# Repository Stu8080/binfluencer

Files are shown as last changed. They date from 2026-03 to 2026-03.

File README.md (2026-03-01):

# Binfluencer

A Leeds bin collection reminder built on the Seeed XIAO ESP32-S3. It queries the live Leeds City Council bin API each day and pulses WS2812B LEDs the evening before your bins are due — so you never forget to put them out.

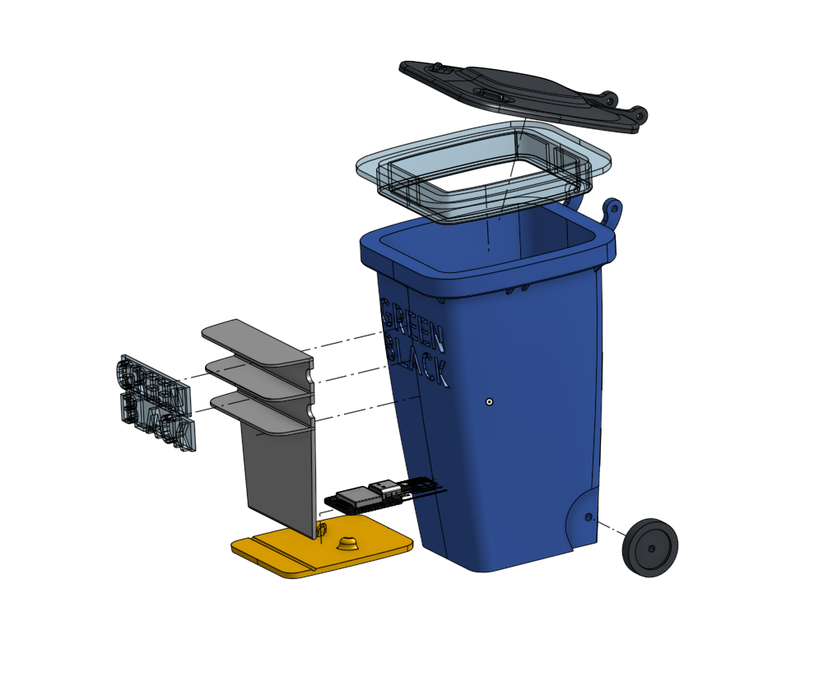
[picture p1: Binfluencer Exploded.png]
Binfluencer Exploded View


---

## How it works

- On boot it connects to WiFi, syncs time via NTP, and fetches your next collection dates from [bins.felixyeung.com](https://bins.felixyeung.com)
- Every **60 seconds** it re-evaluates the schedule (a brief white pulse on the alert strip confirms it's alive)
- Every **24 hours** it re-fetches from the API
- From **7 PM the evening before** a collection, the relevant LEDs start breathing
- On the **collection day itself** the LEDs switch off (bin is already out)

### LED behaviour

| Situation | LEDs |
|---|---|
| Recycling tomorrow evening | Green lettering breathes |
| General waste tomorrow evening | BLACK lettering breathes white |
| Both due tomorrow | Sequences: alert strip → black → green (5 s each) |
| Collection day | All off |
| Schedule check heartbeat | Middle 3 alert strip LEDs pulse once at 50% |

Only one LED channel is ever active at a time to minimise peak current draw.

---

## The enclosure

The housing is a 3D printed miniature wheelie bin. All parts are included in this repo. You will need some 2mm brass rod for the lid hinge and wheels.

### Parts

| File | Material | Notes |
|---|---|---|
| `Wheelie Bin - Bin.stl` | PLA — any colour | Main bin body. Printed in Sunlu Midnight Black |
| `Wheelie Bin - Lid.stl` | PLA — any colour | Snap-fit lid |
| `Wheelie Bin - BLACK.stl` | Translucent PETG | "BLACK" lettering panel, snaps into front of bin |
| `Wheelie Bin - GREEN.stl` | Translucent PETG | "GREEN" lettering panel, snaps into front of bin |
| `Wheelie Bin - Top Light.stl` | Translucent PETG | Alert strip diffuser, seals between lid and bin body |
| `Wheelie Bin - Part 7.stl` | PLA | F-shaped LED mount and light baffle — isolates the two 3-LED channels |
| `Wheelie Bin - Part 8.stl` | PLA | Electronics backing plate |
| `Wheelie Bin - Wheel 1.stl` | PLA | Decorative wheel |
| `Wheelie Bin - Wheel 2.stl` | PLA | Decorative wheel |

Microcontroller used: SEEED Studio's Xiao ESP32-S3: https://thepihut.com/products/seeed-studio-xiao-esp32s3

### Assembly

1. Mount the XIAO ESP32-S3 onto the yellow base plate. You can use a little hot glue or double sided tape. Make sure you've wired +Ve and -Ve to 5v and the three data pins for the addressable LED's
2. Attach the 3-LED strips to the front side of the F-shaped baffle — one strip behind the GREEN lettering, one behind BLACK
3. Snap the translucent GREEN and BLACK lettering panels into the front of the bin
4. Seat the F-shaped assembly inside the bin body, theres a small retainer on the walls to snap it into place
5. Mount the 10-LED alert strip horizontally at the top of the bin light panel, facing outwards — it seals against the lid when closed and glows around the lid edge
6. Close the lid

---

## Hardware

| Component | Details |
|---|---|
| Microcontroller | Seeed XIAO ESP32-S3 |
| LEDs | WS2812B — 3× green channel, 3× black channel, 10× alert strip |
| Power | 5V pin on XIAO → LED +ve; GND → LED −ve |
| Data lines | Separate per channel (not daisy-chained) |

### Wiring

> **Note:** On the XIAO ESP32-S3 the physical D-pin labels do not match GPIO numbers from D6 onwards.

| Physical pin | GPIO | Connect to |
|---|---|---|
| D7 | GPIO 44 | BLACK bin LEDs (3×) |
| D8 | GPIO 7 | GREEN bin LEDs (3×) |
| D9 | GPIO 8 | Alert strip (10×) |
| 5V | — | LED +ve (all strips) |
| GND | — | LED −ve (all strips) |

---

## Software

Built with [PlatformIO](https://platformio.org/) for Arduino framework.

### Dependencies

| Library | Version |
|---|---|
| FastLED | `~3.9.0` (pinned — 3.10.x has a build issue on ESP-IDF 5.3) |
| ArduinoJson | `^7.0.0` |

### Project structure

```
binfluencer/
├── platformio.ini          ← main firmware
├── src/
│   ├── main.cpp            ← setup / loop / LED evaluation
│   ├── config.example.h    ← copy to config.h and fill in your details
│   ├── bins_api.h          ← Leeds bin collection API client
│   ├── led_controller.h    ← FastLED state machine
│   ├── schedule.h          ← date parsing and alert logic
│   └── wifi_manager.h      ← WiFi connection with backoff
└── test_led/               ← standalone LED test (no WiFi/API needed)
    ├── platformio.ini
    └── src/
        ├── main.cpp        ← cycles alert → black → green, 5 s each
        ├── config.h
        └── led_controller.h
```

---

## Setup

### 1. Configure

```bash
cp src/config.example.h src/config.h
```

Edit `src/config.h`:

```cpp
#define WIFI_SSID     "your-ssid"
#define WIFI_PASSWORD "your-password"

#define BINS_POSTCODE "LS1 1AA"   // your postcode
#define BINS_HOUSE    "1"         // your house number
```

Find your premises on [bins.felixyeung.com](https://bins.felixyeung.com) to confirm your postcode and house number are recognised. The premises ID is cached to flash (NVS) after the first successful lookup.

### 2. Flash

```bash
# Main firmware
cd binfluencer
pio run --target upload

# LED test only (no WiFi required)
cd binfluencer/test_led
pio run --target upload
```

### 3. Monitor

```bash
pio device monitor
```

On a successful boot you should see:

```
=== Binfluencer booting ===
[WiFi] Connected. IP: 192.168.x.x
[BOOT] Local time: 2026-03-01 19:00:00 GMT
[API] Found premises: "<<address>>" → id=983201
[Schedule] Next Recycling:    2026-03-06
[Schedule] Next General Waste: 2026-03-13
[BOOT] Setup complete.
```

---

## API

Collection data is sourced from [bins.felixyeung.com](https://bins.felixyeung.com), an unofficial Leeds City Council bin collection API.

```
GET /api/premises?postcode=LS8%201AU
GET /api/jobs?premises={id}
```

The premises ID is stored in NVS after the first lookup so the device only hits the premises endpoint once.

---

## Licence

MIT

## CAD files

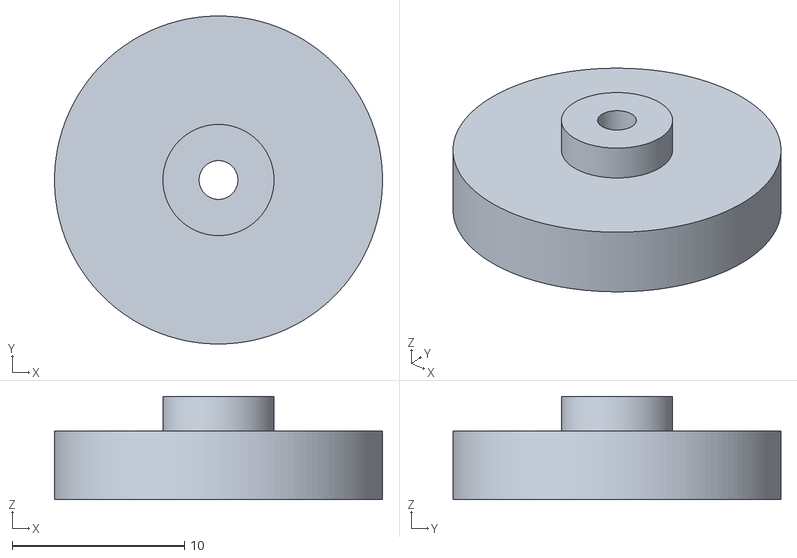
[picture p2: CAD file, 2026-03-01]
Wheelie Bin - Wheel 2.stl.stl
19.1 x 19.1 x 6.00

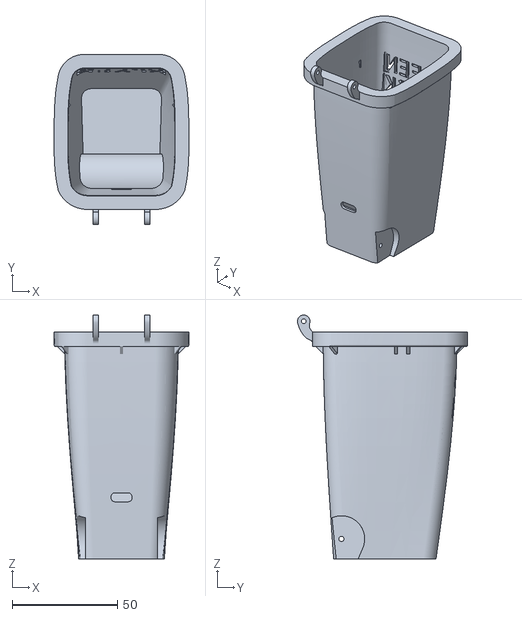
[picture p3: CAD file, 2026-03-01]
Wheelie Bin - Bin.stl.stl
64.1 x 80.9 x 116.0

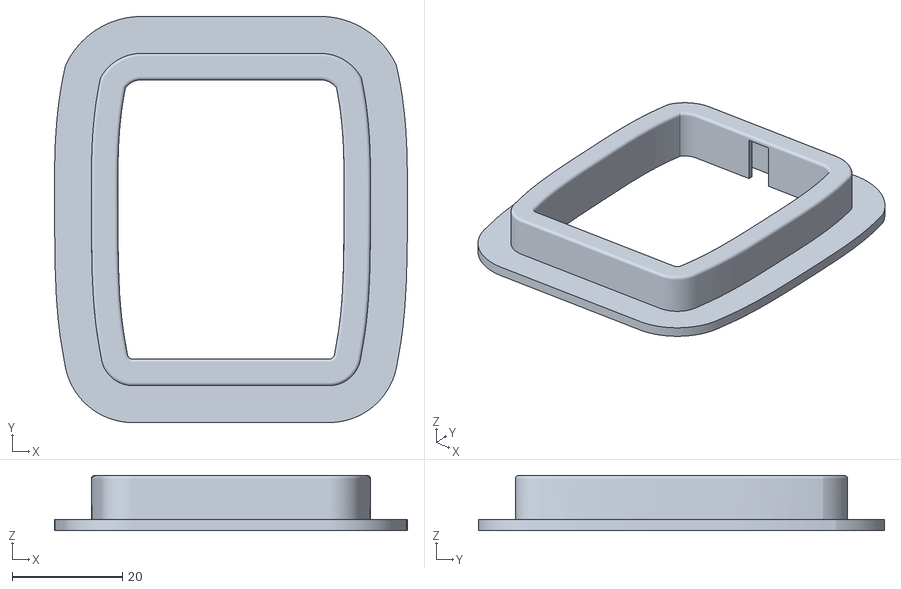
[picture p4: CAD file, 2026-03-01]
Wheelie Bin - Top Light.stl.stl
64.1 x 73.7 x 10.0

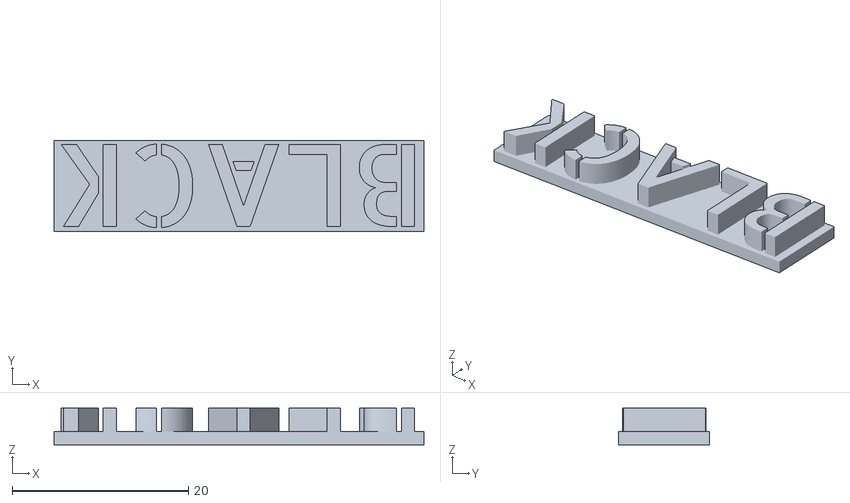
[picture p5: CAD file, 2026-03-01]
Wheelie Bin - BLACK.stl.stl
42.0 x 10.3 x 4.15

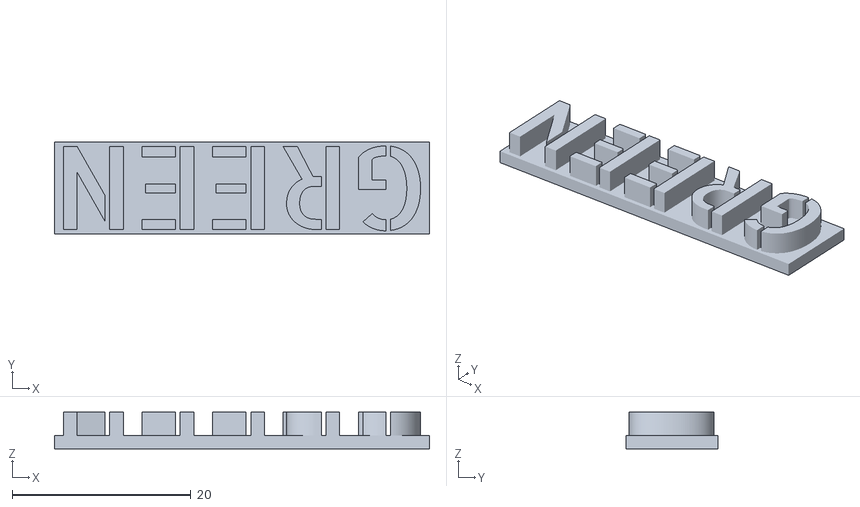
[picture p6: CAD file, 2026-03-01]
Wheelie Bin - GREEN.stl.stl
42.0 x 10.3 x 4.10

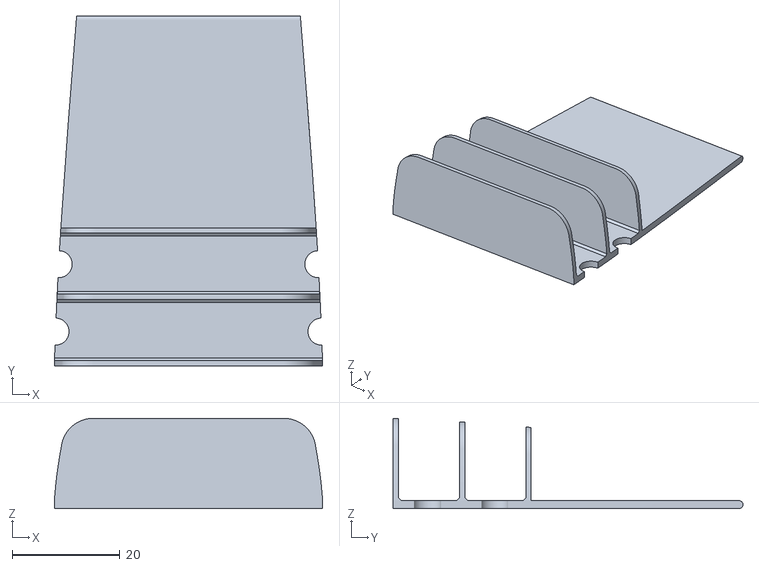
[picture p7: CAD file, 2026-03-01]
Wheelie Bin - Part 8.stl.stl
49.8 x 64.9 x 16.7

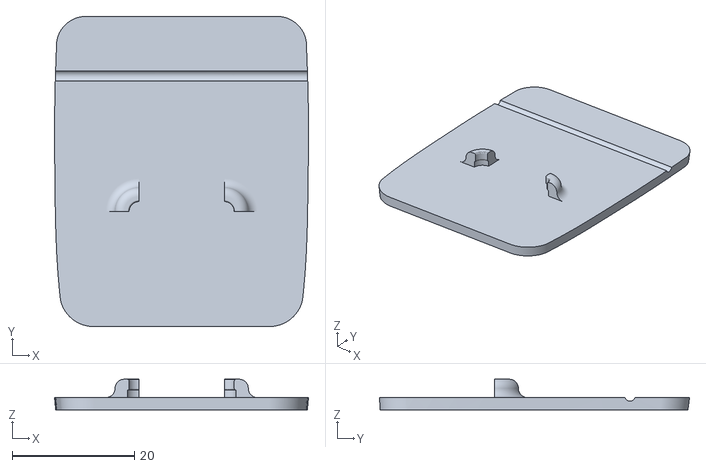
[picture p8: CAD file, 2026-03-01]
Wheelie Bin - Part 7.stl.stl
41.5 x 50.7 x 5.00

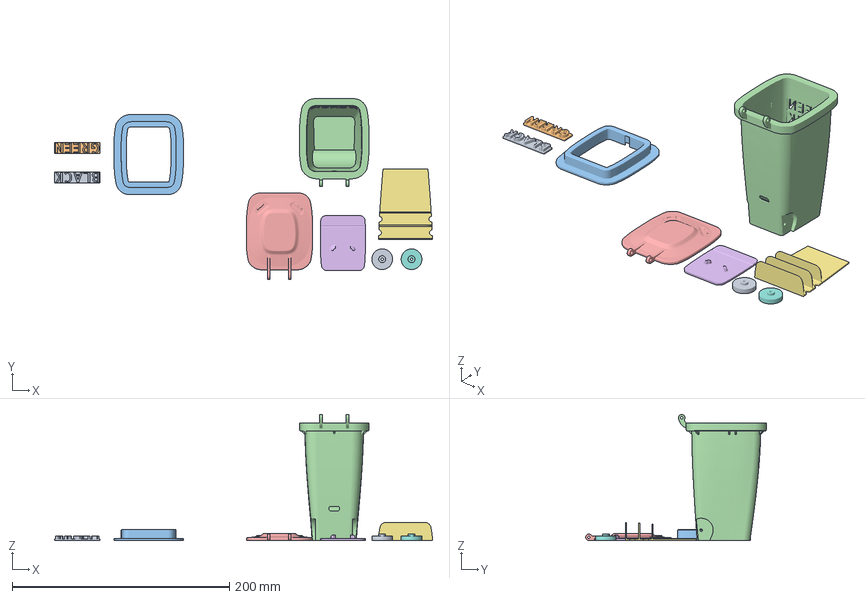
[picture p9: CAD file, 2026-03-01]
Binfluencer.3mf
347.8 x 166.2 x 116.0 mm
Wheelie Bin - BLACK.stl
Wheelie Bin - GREEN.stl
Wheelie Bin - Top Light.stl
Wheelie Bin - Bin.stl
Wheelie Bin - Lid.stl
Wheelie Bin - Part 7.stl
Wheelie Bin - Part 8.stl
Wheelie Bin - Wheel 1.stl
Wheelie Bin - Wheel 2.stl

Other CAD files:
Wheelie Bin - Wheel 1.stl.stl

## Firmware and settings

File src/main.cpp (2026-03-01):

#include <Arduino.h>
#include "config.h"
#include "wifi_manager.h"
#include "bins_api.h"
#include "led_controller.h"
#include "schedule.h"

// ----------------------------------------------------------------
// Globals
// ----------------------------------------------------------------
static BinSchedule g_schedule;
static uint32_t    g_lastApiRefresh    = 0;
static uint32_t    g_lastScheduleCheck = 0;
static bool        g_apiReady          = false;

// ----------------------------------------------------------------
// Forward declarations
// ----------------------------------------------------------------
bool refreshApi();
void evaluateAndSetLeds();

// ----------------------------------------------------------------
// setup()
// ----------------------------------------------------------------
void setup() {
    Serial.begin(115200);
    delay(500);   // wait for serial monitor to attach
    Serial.println("\n=== Binfluencer booting ===");

    // 1. Initialise LEDs (all off)
    LedController::begin();

    // 2. Connect to WiFi
    if (!WifiManager::connect()) {
        Serial.println("[BOOT] WiFi failed — retrying on next loop.");
    }

    // 3. Sync time via NTP (blocks until time is set, up to ~5 s)
    if (WifiManager::isConnected()) {
        Serial.println("[BOOT] Syncing NTP time...");
        configTzTime(TZ_INFO, NTP_SERVER);

        // Wait for NTP sync (up to 10 s)
        struct tm timeInfo;
        uint8_t attempts = 0;
        while (!getLocalTime(&timeInfo) && attempts < 20) {
            delay(500);
            ++attempts;
        }
        if (getLocalTime(&timeInfo)) {
            char buf[64];
            strftime(buf, sizeof(buf), "%Y-%m-%d %H:%M:%S %Z", &timeInfo);
            Serial.printf("[BOOT] Local time: %s\n", buf);
        } else {
            Serial.println("[BOOT] NTP sync timed out — time may be wrong.");
        }
    }

    // 4. Fetch premises ID (NVS cache or API) and collection dates
    g_apiReady = refreshApi();

    // 5. Initial LED evaluation
    evaluateAndSetLeds();

    Serial.println("[BOOT] Setup complete.\n");
}

// ----------------------------------------------------------------
// loop()
// ----------------------------------------------------------------
void loop() {
    uint32_t now = millis();

    // --- Re-fetch API once per day ---
    if (g_apiReady && (now - g_lastApiRefresh >= API_REFRESH_MS)) {
        Serial.println("[LOOP] Daily API refresh.");
        refreshApi();
        evaluateAndSetLeds();
    }

    // --- Retry if initial API fetch failed (check every 60 s) ---
    if (!g_apiReady && (now - g_lastApiRefresh >= SCHEDULE_CHECK_MS)) {
        if (WifiManager::ensureConnected()) {
            g_apiReady = refreshApi();
            if (g_apiReady) evaluateAndSetLeds();
        }
    }

    // --- Periodic schedule check ---
    if (g_apiReady && (now - g_lastScheduleCheck >= SCHEDULE_CHECK_MS)) {
        g_lastScheduleCheck = now;
        evaluateAndSetLeds();
    }

    // --- Animate LEDs ---
    LedController::tick();

    delay(20);   // ~50 fps animation tick
}

// ----------------------------------------------------------------
// refreshApi(): fetch premises ID then collection dates.
// Updates g_schedule and g_lastApiRefresh.
// Returns true on success.
// ----------------------------------------------------------------
bool refreshApi() {
    if (!WifiManager::ensureConnected()) {
        Serial.println("[API] No WiFi — skipping refresh.");
        return false;
    }

    String premId = BinsApi::getPremisesId();
    if (premId.isEmpty()) {
        Serial.println("[API] Could not get premises ID.");
        return false;
    }

    if (!BinsApi::getCollectionDates(premId, g_schedule)) {
        Serial.println("[API] Could not get collection dates.");
        return false;
    }

    Schedule::printSchedule(g_schedule);
    g_lastApiRefresh = millis();
    return true;
}

// ----------------------------------------------------------------
// evaluateAndSetLeds(): decide which LED mode to apply right now.
// ----------------------------------------------------------------
void evaluateAndSetLeds() {
    LedController::heartbeat();

    // If today IS a collection day → clear LEDs (bin already out)
    bool recyclingToday    = Schedule::isToday(g_schedule.recyclingDate);
    bool generalWasteToday = Schedule::isToday(g_schedule.generalWasteDate);

    if (recyclingToday || generalWasteToday) {
        Serial.println("[SCHED] Collection day — LEDs off.");
        LedController::setMode(LedMode::OFF);
        return;
    }

    // Evaluate whether this evening is the night before a collection
    bool alertR = false, alertG = false;
    Schedule::evaluate(g_schedule, alertR, alertG);

    if (alertR && alertG) {
        LedController::setMode(LedMode::BOTH);
    } else if (alertR) {
        LedController::setMode(LedMode::RECYCLING);
    } else if (alertG) {
        LedController::setMode(LedMode::GENERAL_WASTE);
    } else {
        LedController::setMode(LedMode::OFF);
    }
}

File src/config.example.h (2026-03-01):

#pragma once

// ============================================================
// WiFi credentials — fill in before flashing
// ============================================================
#define WIFI_SSID     "your-ssid"
#define WIFI_PASSWORD "your-password"

// ============================================================
// Bin collection address
// Filter: premises whose addressNumber matches BINS_HOUSE
// Find your postcode/house via https://bins.felixyeung.com
// ============================================================
#define BINS_POSTCODE "LS1 1AA"
#define BINS_HOUSE    "1"

// ============================================================
// LED pins (XIAO-ESP32-S3: D7=GPIO44, D8=GPIO7, D9=GPIO8)
// Adjust to match your wiring.
// ============================================================
#define PIN_GREEN_BIN    7  // D8 — 3 LEDs, green recycling bin
#define PIN_BLACK_BIN   44  // D7 — 3 LEDs, black general waste bin
#define PIN_ALERT_STRIP  8  // D9 — 10 LEDs, general alert strip

#define LED_COUNT_GREEN 3
#define LED_COUNT_BLACK 3
#define LED_COUNT_ALERT 10

// ============================================================
// Alert window — LEDs activate on the EVENING BEFORE collection
// ============================================================
#define ALERT_HOUR 19   // 7:00 PM — adjust to taste (24-hour clock)
#define ALERT_MIN   0

// ============================================================
// API re-poll interval — once per day
// ============================================================
#define API_REFRESH_MS (24UL * 60UL * 60UL * 1000UL)

// ============================================================
// Schedule check interval — how often loop() evaluates LED state
// ============================================================
#define SCHEDULE_CHECK_MS (60UL * 1000UL)   // every 60 seconds

// ============================================================
// NTP / timezone
// ============================================================
#define NTP_SERVER "pool.ntp.org"
#define TZ_INFO    "GMT0BST,M3.5.0/1,M10.5.0"   // UK (handles BST/GMT automatically)

// ============================================================
// NVS (Preferences) storage
// ============================================================
#define NVS_NAMESPACE  "binfluencer"
#define NVS_KEY_PREM   "prem_id"

// ============================================================
// LED animation
// ============================================================
#define BREATHE_PERIOD_MS 3000   // breathing cycle length in ms
#define BREATHE_MIN_VAL     20   // minimum brightness (0-255)
#define BREATHE_MAX_VAL    220   // maximum brightness (0-255)

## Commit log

2026-03-01 Initial commit — Binfluencer firmware
    ESP32-S3 (Seeed XIAO) device that queries the Leeds bin collection
    API (bins.felixyeung.com) and pulses WS2812B LEDs the evening before
    collection day. Includes standalone LED test project.
2026-03-01 Add README
    Full project documentation covering hardware, wiring, 3D printed
    enclosure, assembly, software setup and API details.
